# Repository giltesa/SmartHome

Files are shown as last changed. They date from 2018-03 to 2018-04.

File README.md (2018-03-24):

# SmartHome

**SmartHome** es la segunda versión de mi proyecto de **hardware** para la automatización del hogar, esta vez por comunicación inalámbrica y compatible con [**MySensors**](https://github.com/mysensors/MySensors/tree/master).

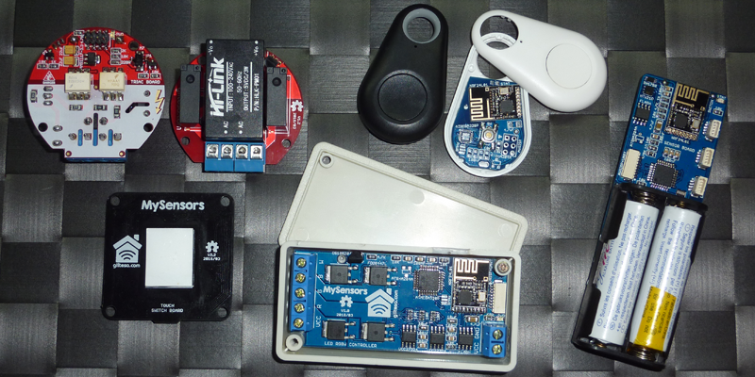
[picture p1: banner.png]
Banner SmartHome


## Introducción

En este repositorio encontraras la documentación para construir los diferentes nodos disponibles, eso incluye los esquemáticos, los circuitos, los gerbers, piezas en 3D, código fuente, etc.

La funcionalidad de los nodos varia dependiendo de la tarea para la que hayan sido construidos. Por ejemplo encontraras un nodo de interruptor táctil para sustituir los interruptores de la pared y que permite encender, apagar y *regular el brillo (en desarrollo)* de las lamparas del techo de las habitaciones. También encontraras un nodo para tomar mediciones de temperatura, humedad y luz así como capaz de detectar eventos como la apertura y cierre de puertas y ventanas. Un poco mas abajo hay disponible una lista de todos los nodos diseñados.

### Requisitos previos

Los nodos funcionan por comunicación inalámbrica RF a 2.4Ghz distinta del WiFi por lo que hace falta un Gateway capaz de convertir esa comunicación inalámbrica a cableada y viceversa, esto tiene como inconveniente que hace falta un aparato mas pero tiene como ventaja que no sobrecargaremos el router WiFi con una treintena de nodos conectados al mismo tiempo.

Además del Gateway también es necesario un software de gestión que controle todos los nodos, este software puede ser cualquiera que soporte nodos programados con la librería MySensors, en el apartado [controlador](https://www.mysensors.org/controller) hay documentada una tabla de softwares de gestión compatibles.

## Lista de nodos

Esta es la lista de todos los nodos con un estado de desarrollo avanzado pero no finalizado. Para consultar su estado actual o próximos nodos que desarrollare visitar este panel de trabajo: [Trello SmartHome](https://trello.com/b/6nWJ42Qx/smarthome)

* Interruptor táctil de relés
* Interruptor táctil de relé+triac
* Sensor multiuso
* Mando a distancia
* Regulador de luz LED RGBW

## Licencia

Este proyecto está licenciado bajo la licencia **Creative Commons** de tipo: **[Reconocimiento-NoComercial-CompartirIgual 4.0 Internacional (CC BY-NC-SA 4.0)](https://creativecommons.org/licenses/by-nc-sa/3.0/deed.es_ES)**. Consulte el archivo [LICENSE.md](LICENSE.md) para obtener más información.

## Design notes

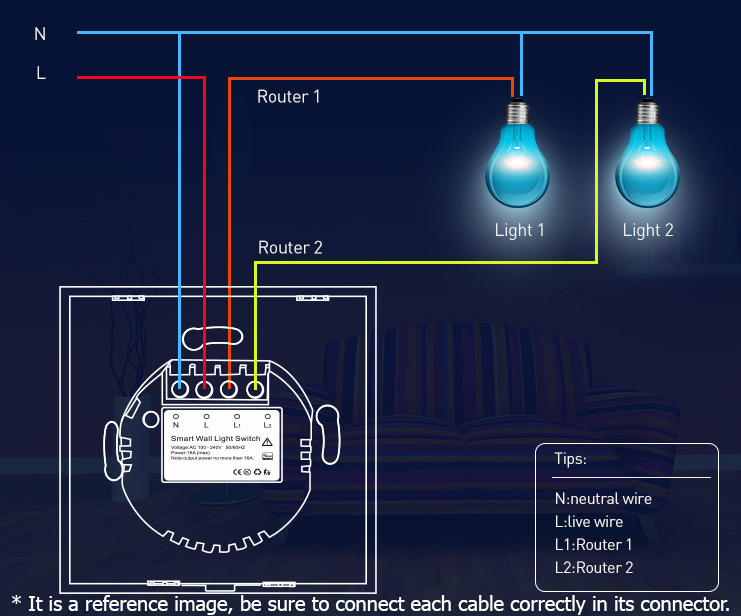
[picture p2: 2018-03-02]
2. Touch switch/4. Documentation/2. Relay Board/Pinout.png

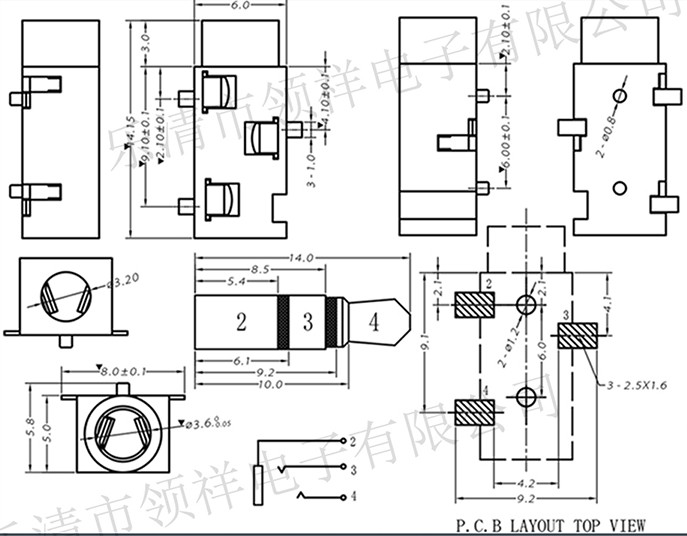
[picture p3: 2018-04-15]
7. Current sensor/4. Documentation/Pinout Jack 3.5mm.jpg

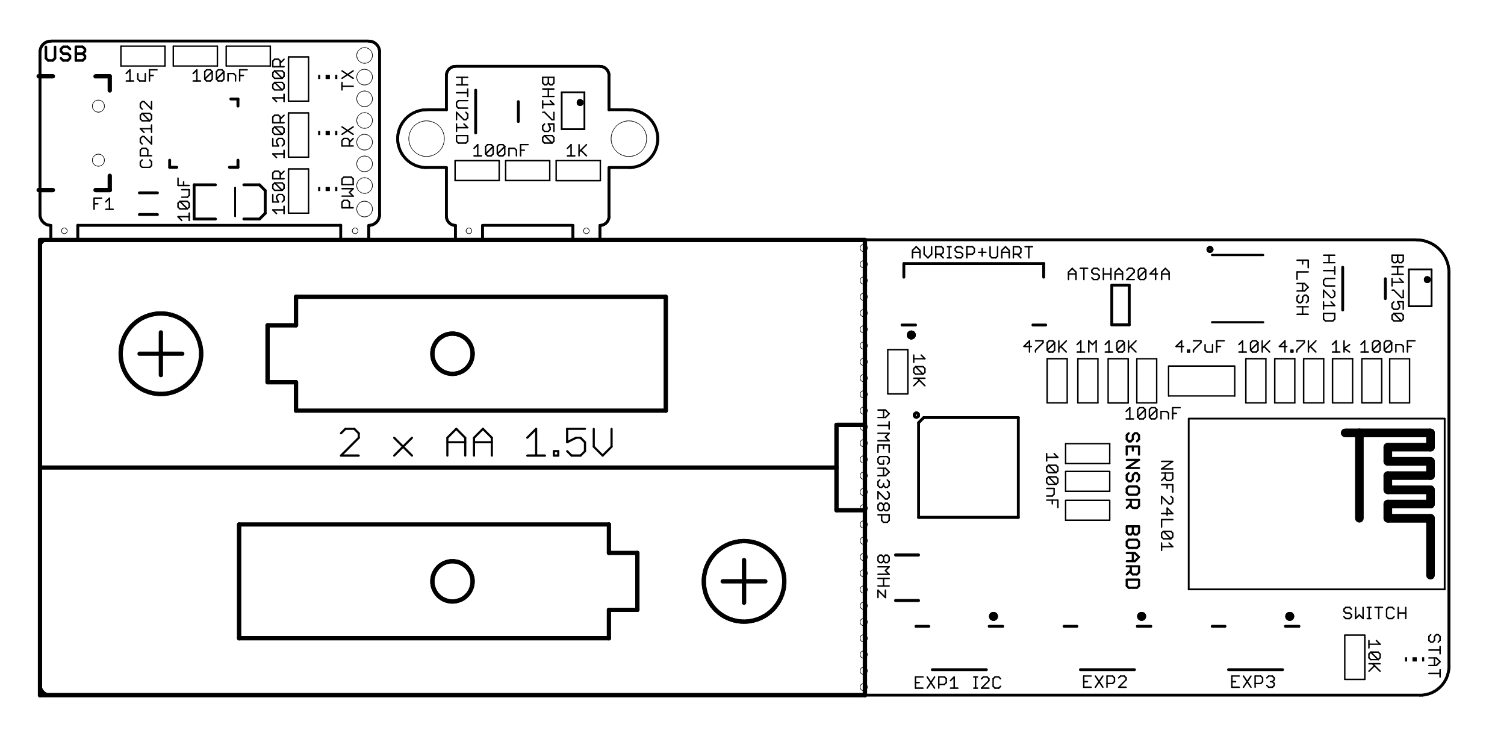
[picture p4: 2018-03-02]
3. Sensor/2. Gerbers/Images/Sensor.GTO.png

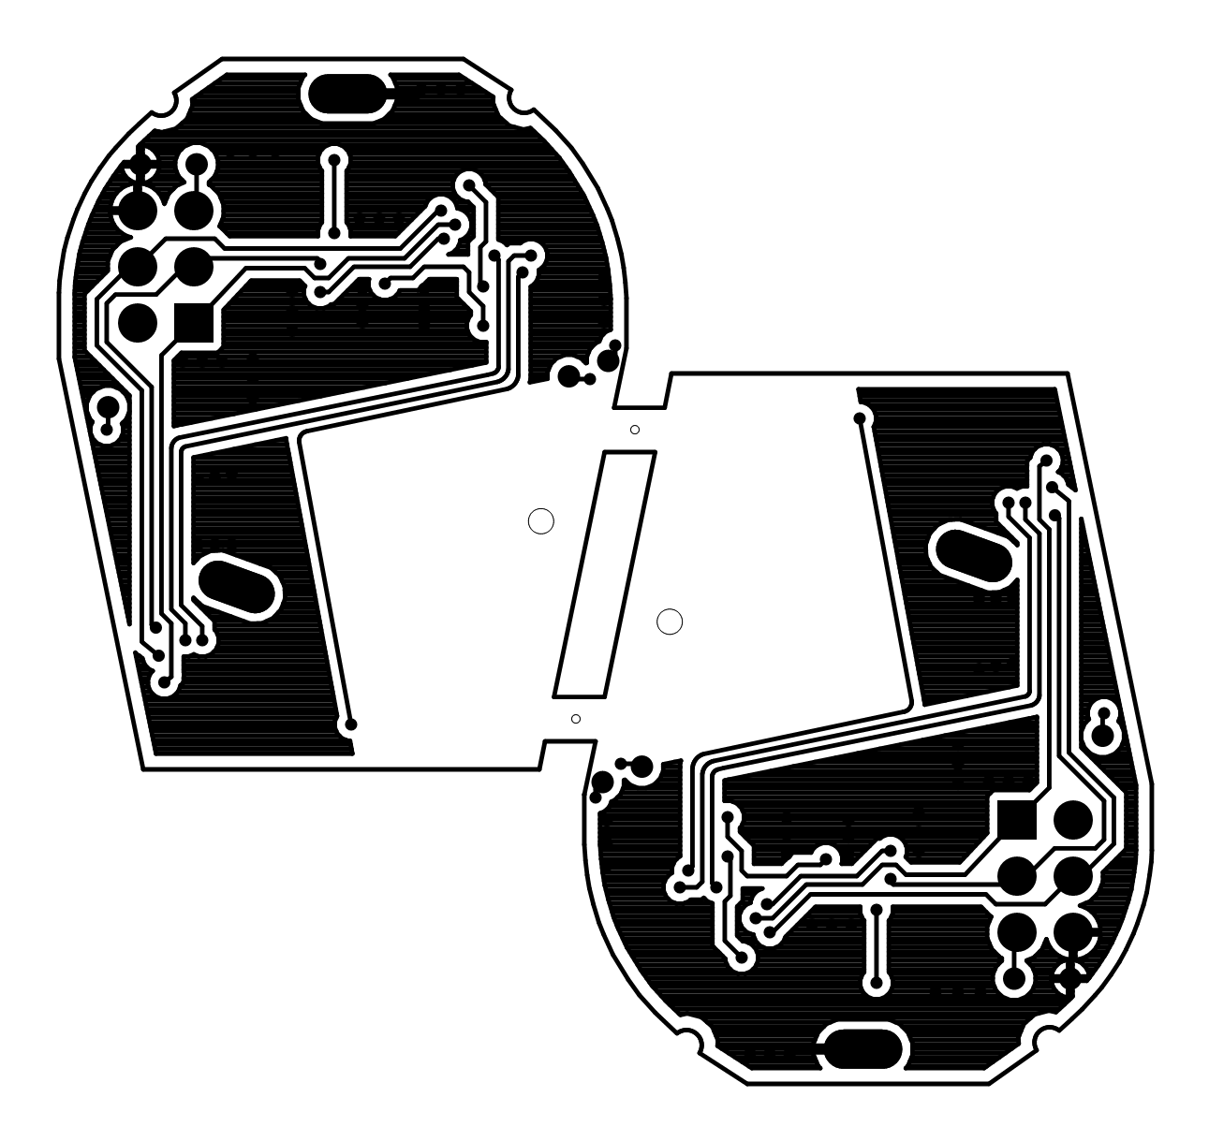
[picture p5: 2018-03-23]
4. Remote Control/2. Gerbers/Images/Remote Control - x2.GBL.png

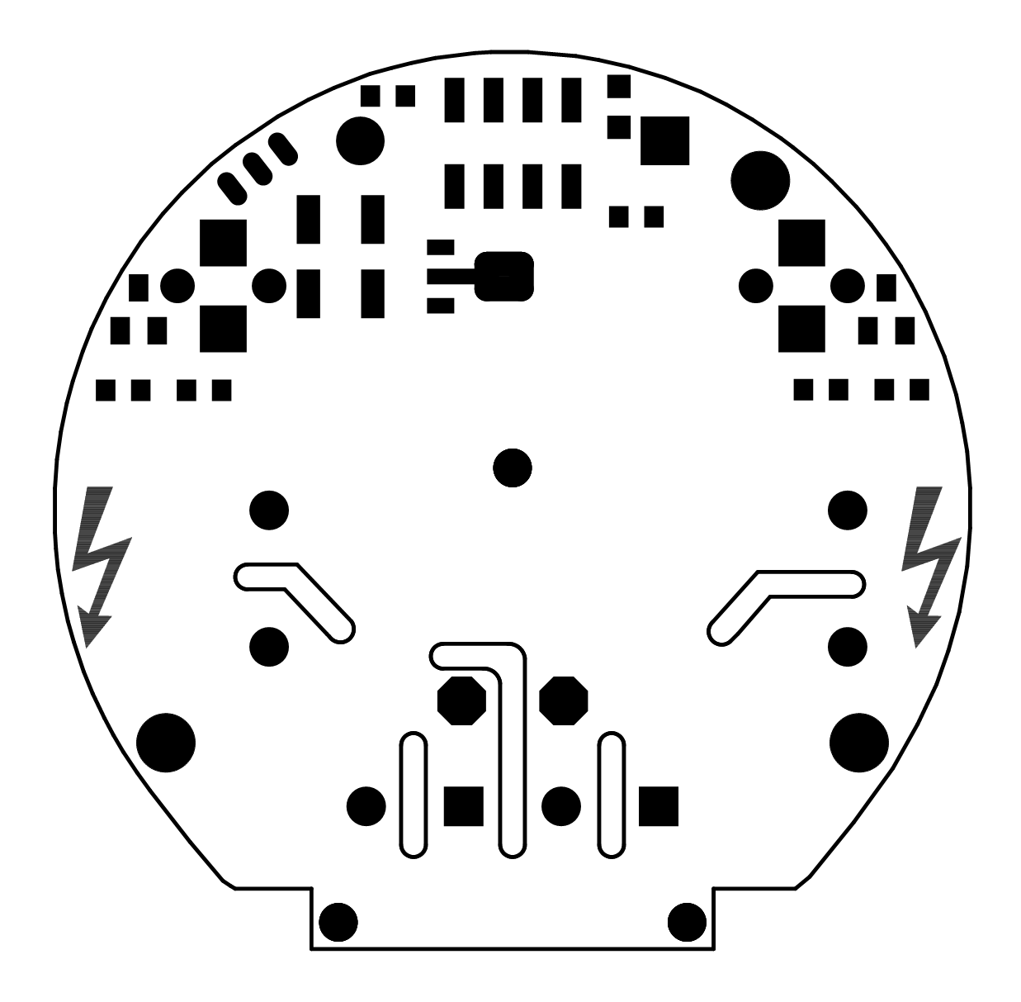
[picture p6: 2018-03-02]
2. Touch switch/2. Gerbers/2. Relay Switch/Relay Switch - 2018-03 v1.2/Images/Relay Switch.GTS.png

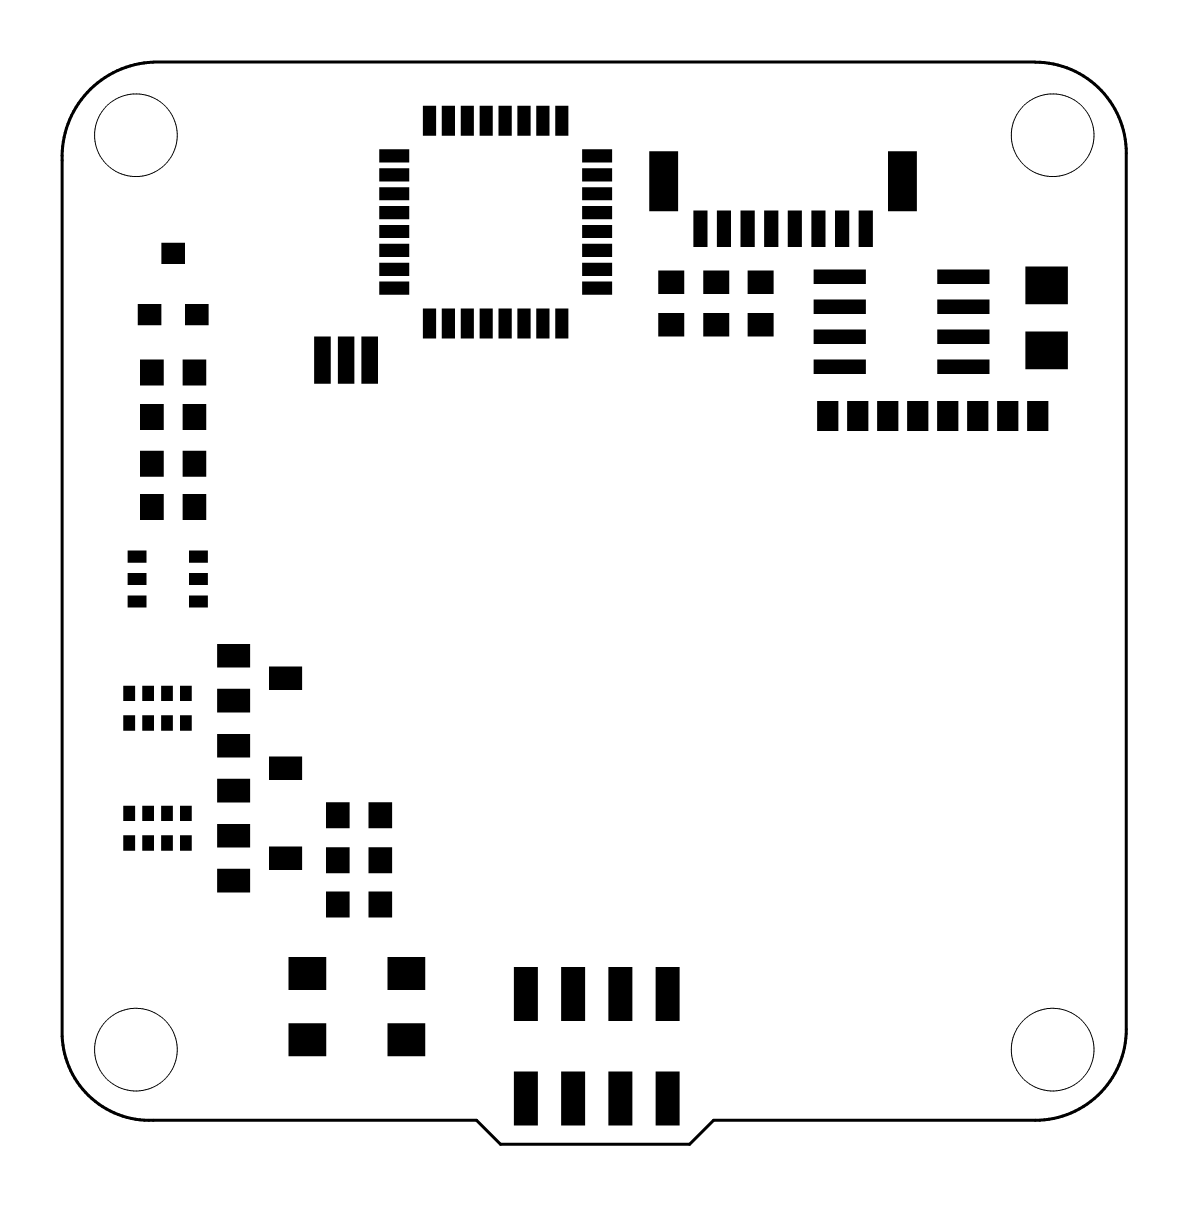
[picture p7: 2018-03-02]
2. Touch switch/2. Gerbers/1. Touch Switch/Touch Switch - 2017-12 v2.1/Images/SmartHome - Switch Touch.GTP.png

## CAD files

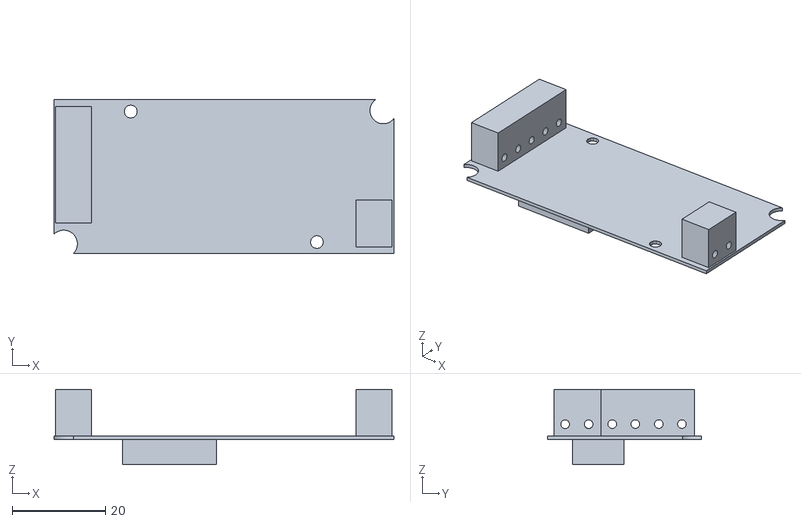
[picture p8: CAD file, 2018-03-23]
5. LED RGBW Controller/3. Renders/Sketchup/Drilling guide.stl
73.0 x 33.1 x 16.2

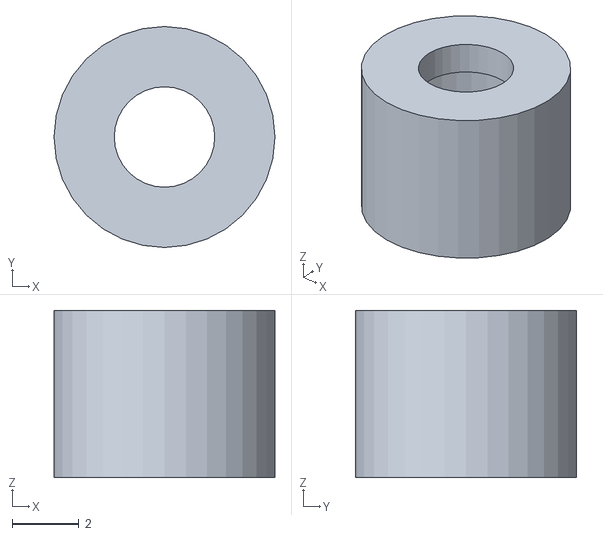
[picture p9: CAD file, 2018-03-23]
5. LED RGBW Controller/3. Renders/Sketchup/washer.stl
6.60 x 6.60 x 5.00

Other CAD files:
5. LED RGBW Controller/3. Renders/Sketchup/Drilling guide.skp
5. LED RGBW Controller/3. Renders/Sketchup/washer.skp
7. Current sensor/3. Renders/DinBox.skp

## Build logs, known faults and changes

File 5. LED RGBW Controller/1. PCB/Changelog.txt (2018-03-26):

--- YYYY/MM -------------------------------------------------------------------------------------------------

    + REMOTE CONTROL Vx.x.
        - Change the voltage regulator from 24 to 5V, if the power supply provides more than 24V will burn,
          it would be good to use one that had more margin.

--- 2018/03 INITIAL VERSION ---------------------------------------------------------------------------------

    + LED RGBW CONTROLLER V1.0.

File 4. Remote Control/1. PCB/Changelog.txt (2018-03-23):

--- 2018/04 -------------------------------------------------------------------------------------------------

    + REMOTE CONTROL V1.1.
        - Change the encapsulation of the microcontroller from QFN28 to MLF32... I got confused and it is cheaper to make the boards again than to buy the correct microcontrollers.
        - Make the PCB with 1mm thickness.
        - Change the button component from 6x6 to 5x5mm
        - Adjust the size of the PCB so that it is as close as possible to the housing.

--- 2018/03 INITIAL VERSION ---------------------------------------------------------------------------------

    + REMOTE CONTROL V1.0.

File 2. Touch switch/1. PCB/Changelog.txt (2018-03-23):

--- 2018/03 -------------------------------------------------------------------------------------------------

    + TOUCH SWITCH BOARD V2.2:
        - Change pinout.

    + RELAY SWITCH BOARD V1.2:
        - Change AC connectors by ones at an angle of 90º (and modify the plastic shell with the new design)
        - Change encapsulated for AMS1117 to SOT89 (To match the triacs PCB)

    + TRIAC SWITCH BOARD V1.0:
        - Initial version

--- 2017/12 -------------------------------------------------------------------------------------------------

    + TOUCH SWITCH BOARD V2.1:
        - Move programming connector to the inside of the board, it was colliding with the plastic housing.
        - Modify the pinout of the RGB LED, the green and blue colors of the reverse.
        - Add text that identifies the functionality of the board.

    + RELAY SWITCH BOARD V1.1:
        - Replace SSR relay with 5A mechanical relays.
        - Add text that identifies the functionality of the board.

--- 2017/10 INITIAL VERSION ---------------------------------------------------------------------------------

    + TOUCH SWITCH BOARD V2.0

    + RELAY SWITCH BOARD V1.0

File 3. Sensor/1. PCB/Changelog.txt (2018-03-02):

--- 2018/03 INITIAL VERSION ---------------------------------------------------------------------------------

    + SENSOR V1.0.

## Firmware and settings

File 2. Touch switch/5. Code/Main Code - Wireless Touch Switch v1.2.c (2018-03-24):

/**
 * Name:     Smarthome: Touch Switch Two Light
 * Autor:    Alberto Gil Tesa
 * Web:      https://giltesa.com/smarthome
 *           https://giltesa.com/?p=18460
 * License:  CC BY-NC-SA 4.0
 * Version:  1.2
 * Date:     2018/03/24
 *
 */



/**
 *  Pinout Touch Switch Board V2.2 and Relay Switch Board V1.2
 */
#define pBTN        2 //Interruption
#define pZERO       3 //Interruption (Not used)
#define pRELAY_1   A1
#define pRELAY_2   A2
#define pNRF_CE     7
#define pNRF_CS    10
#define pLED_RED    5 //PWM
#define pLED_GREEN  6 //PWM
#define pLED_BLUE   9 //PWM
#define pFLASH_CS   8
#define pDS18B20   A0
#define pATSHA204A A3



/**
 * MySensor configuration:
 */
#define MY_DEBUG                                // Enable debug prints to serial monitor
#define MY_BAUD_RATE                9600        // Serial output baud rate
#define MY_TRANSPORT_WAIT_READY_MS  1000        // Set how long to wait for transport ready in milliseconds
#define MY_RADIO_NRF24                          // Enable and select radio type attached
#define MY_RF24_CE_PIN              pNRF_CE     // Define this to change the chip enable pin from the default
#define MY_RF24_CS_PIN              pNRF_CS     // Define this to change the chip select pin from the default
//#define MY_REPEATER_FEATURE                   // Enable repeater functionality for this node
#define MY_OTA_FIRMWARE_FEATURE                 // Define this in sketch to allow safe over-the-air firmware updates
//#define MY_OTA_FLASH_SS           pFLASH_CS   // Slave select pin for external flash. (The bootloader must use the same pin)
#define MY_OTA_FLASH_JDECID         0xEF30      // https://forum.mysensors.org/topic/4267/w25x40clsnig-as-flash-for-ota

#define MS_BOARD_NAME               "Touch Switch: Two light"
#define MS_SOFTWARE_VERSION         "1.2"
#define MS_RELAY1_CHILD_ID          0
#define MS_RELAY2_CHILD_ID          1
#define MS_LEDPWM_CHILD_ID          2
#define MS_TEMP_CHILD_ID            3

#include <MySensors.h>
#include <OneWire.h>
#include <DallasTemperature.h>
#include <AsyncTaskLib.h>

MyMessage msgR1(MS_RELAY1_CHILD_ID, V_STATUS);
MyMessage msgR2(MS_RELAY2_CHILD_ID, V_STATUS);
MyMessage msgT1(MS_TEMP_CHILD_ID,   V_TEMP);

DallasTemperature ds18b20(new OneWire(pDS18B20));

AsyncTask *taskOn, *taskOff, *taskTemp;
byte brightnessLed = 255;

         const  unsigned long tDebouncePress = 50;
         const  unsigned long tWaitTwoPress  = 400;
         const  unsigned long tShortPress    = 300;
volatile static unsigned long tBtnPressed1   = 0;
volatile static unsigned long tBtn1Released1 = 0;
volatile static unsigned long tBtnPressed2   = 0;
volatile static unsigned long tBtn1Released2 = 0;
         static boolean       sBtnPressed    = false;



/**
 * For initialisations that needs to take place before MySensors transport has been setup (eg: SPI devices).
 */
void before()
{
    pinMode(pBTN,       INPUT);
    pinMode(pLED_RED,   OUTPUT);
    pinMode(pLED_GREEN, OUTPUT);
    pinMode(pLED_BLUE,  OUTPUT);
    pinMode(pRELAY_1,   OUTPUT);
    pinMode(pRELAY_2,   OUTPUT);

    attachInterrupt(digitalPinToInterrupt(pBTN), btnInterrupt,  CHANGE);

    setLedColor('0');
}



/**
 * Called once at startup, usually used to initialize sensors.
 */
void setup()
{
    ds18b20.begin();

    taskOn  = new AsyncTask(4000, [](){ setLedColor('B');   });
    taskOff = new AsyncTask(1000, [](){ refreshLedStatus(); });

    #ifdef MY_DEBUG
        taskTemp = new AsyncTask(60000, true, [](){ sendTemperature(); });
        taskTemp->Start();
    #endif

    request(MS_RELAY1_CHILD_ID, V_STATUS);
    request(MS_RELAY2_CHILD_ID, V_STATUS);
    request(MS_LEDPWM_CHILD_ID, V_DIMMER);

    //Start:
    setLedColor('R');
}



/**
 * This allows controller to re-request presentation and do re-configuring node after startup.
 */
void presentation()
{
    sendSketchInfo(MS_BOARD_NAME, MS_SOFTWARE_VERSION);

    present(MS_RELAY1_CHILD_ID, S_BINARY, "Light 1");
    present(MS_RELAY2_CHILD_ID, S_BINARY, "Light 2");
    present(MS_LEDPWM_CHILD_ID, S_DIMMER, "LED brightness");
    present(MS_TEMP_CHILD_ID,   S_TEMP,   "Internal temp");
}



/**
 * This will be called continuously after setup.
 */
void loop()
{
    #ifdef MY_DEBUG
        taskTemp->Update();
    #endif


    //In case of problems in the wireless connection, the LED flashes blue.
    if( !isTransportReady() )
    {
        if( !taskOn->IsActive() ){
            taskOn->Start();
        }
        taskOn->Update(*taskOff);
        taskOff->Update(*taskOn);
    }
    else if( taskOn->IsActive() || taskOff->IsActive() )
    {
        taskOn->Stop();
        taskOff->Stop();
        refreshLedStatus();
    }


    //Logic for the touch button.
    //Depending on the number of button presses and the duration, one or the other action is carried out:
    if( tBtn1Released1 > 0 && millis() - tBtn1Released1 > tWaitTwoPress && tBtn1Released2 == 0 ) //One pulsation
    {
        sBtnPressed = true;
        if( tBtn1Released1 - tBtnPressed1 <= tShortPress ) //Short press
        {
            digitalWrite(pRELAY_1, !digitalRead(pRELAY_1));
            send(msgR1.set(digitalRead(pRELAY_1)));
        }
        else if( tBtn1Released1 - tBtnPressed1 > tShortPress ) //Long press
        {
            boolean status = ( !digitalRead(pRELAY_1) && !digitalRead(pRELAY_2) );
            digitalWrite(pRELAY_1, status);
            digitalWrite(pRELAY_2, status);
            send(msgR1.set(status));
            send(msgR2.set(status));
        }
    }
    else if( tBtn1Released1 > 0 && tBtn1Released2 > 0 ) //Double pulsation
    {
        sBtnPressed = true;
        digitalWrite(pRELAY_2, !digitalRead(pRELAY_2));
        send(msgR2.set(digitalRead(pRELAY_2)));
    }


    if( sBtnPressed )
    {
        sBtnPressed  = false;
        tBtnPressed1 = tBtn1Released1 = tBtnPressed2 = tBtn1Released2 = 0;
        refreshLedStatus();

        #ifndef MY_DEBUG
            sendTemperature();
        #endif
    }

}



/**
 * Get the time when the button is pressed and released.
 */
void btnInterrupt()
{
    static boolean sInterrupt = false;

    noInterrupts();
    sInterrupt = !sInterrupt;

    if( sInterrupt ){
        setLedColor('0');
    }

    if( tBtn1Released1 == 0 )
    {
        if( sInterrupt ){
            tBtnPressed1 = millis();
        }else{
            tBtn1Released1 = millis();
        }
    }
    else if( tBtn1Released2 == 0 && millis() - tBtn1Released1 > tDebouncePress )
    {
        if( sInterrupt ){
            tBtnPressed2 = millis();
        }else{
            tBtn1Released2 = millis();
        }
    }

    if( !sInterrupt ){
        refreshLedStatus();
    }
    interrupts();
}



/**
 *
 */
void receive(const MyMessage &message)
{
    if( (message.sensor == MS_RELAY1_CHILD_ID || _msg.destination == 255) && message.type == V_STATUS )
    {
        digitalWrite(pRELAY_1, message.getBool());
        refreshLedStatus();
    }
    else if( message.sensor == MS_RELAY2_CHILD_ID && message.type == V_STATUS )
    {
        digitalWrite(pRELAY_2, message.getBool());
        refreshLedStatus();
    }
    else if( message.sensor == MS_LEDPWM_CHILD_ID && message.type == V_DIMMER )
    {
        brightnessLed = map(message.getInt(), 0, 100, 25, 255);
        refreshLedStatus();
    }
}



/**
 *
 */
void sendTemperature()
{
    ds18b20.requestTemperatures();
    send(msgT1.set(getControllerConfig().isMetric ? ds18b20.getTempCByIndex(0) : ds18b20.getTempFByIndex(0), 1));
}



/**
 * Sets the color of the led according to the state of the relays.
 */
void refreshLedStatus()
{
    if( digitalRead(pRELAY_1) && !digitalRead(pRELAY_2) ){
        setLedColor('G');
    }
    else if( !digitalRead(pRELAY_1) && digitalRead(pRELAY_2) ){
        setLedColor('Y');
    }
    else if( digitalRead(pRELAY_1) && digitalRead(pRELAY_2) ){
        setLedColor('W');
    }
    else if( !digitalRead(pRELAY_1) && !digitalRead(pRELAY_2) ){
        setLedColor('R');
    }
}



/**
 * Turn on the led in the indicated color.
 */
void setLedColor( char color )
{
    switch( color )
    {
        case 'R':   //RED
            analogWrite(pLED_RED,    brightnessLed);
            digitalWrite(pLED_GREEN, LOW);
            digitalWrite(pLED_BLUE,  LOW);
            break;
        case 'G':   //GREEN
            digitalWrite(pLED_RED,   LOW);
            analogWrite(pLED_GREEN,  brightnessLed);
            digitalWrite(pLED_BLUE,  LOW);
            break;
        case 'B':   //BLUE
            digitalWrite(pLED_RED,   LOW);
            digitalWrite(pLED_GREEN, LOW);
            analogWrite(pLED_BLUE,  brightnessLed);
            break;
        case 'Y':   //YELLOW
            analogWrite(pLED_RED,    brightnessLed);
            analogWrite(pLED_GREEN,  brightnessLed);
            digitalWrite(pLED_BLUE,  LOW);
            break;
        case 'W':   //WHITE
            analogWrite(pLED_RED,   brightnessLed);
            analogWrite(pLED_GREEN, brightnessLed);
            analogWrite(pLED_BLUE,  brightnessLed);
            break;
        default:    //OFF
            digitalWrite(pLED_RED,   LOW);
            digitalWrite(pLED_GREEN, LOW);
            digitalWrite(pLED_BLUE,  LOW);
            break;
    }
}

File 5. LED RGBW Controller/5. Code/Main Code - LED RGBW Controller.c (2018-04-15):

/**
 * Name:     Smarthome: LED RGBW Controller
 * Autor:    Alberto Gil Tesa
 * Web:      https://giltesa.com/smarthome
 * License:  CC BY-NC-SA 4.0
 * Version:  1.0.2
 * Date:     2018/04/05
 *
 */


/**
 *  Pinout V1.0
 */
#define pLED_RED    5 //PWM
#define pLED_GREEN  6 //PWM
#define pLED_BLUE   9 //PWM
#define pLED_WHITE  3 //PWM
#define pNRF_CE     7
#define pNRF_CS    10
#define pFLASH_CS   8
#define pDS18B20   A0
#define pATSHA204A A3



/**
 * MySensor configuration:
 */
#define MY_DEBUG                                // Enable debug prints to serial monitor
#define MY_BAUD_RATE                9600        // Serial output baud rate
#define MY_TRANSPORT_WAIT_READY_MS  1000        // Set how long to wait for transport ready in milliseconds
#define MY_RADIO_NRF24                          // Enable and select radio type attached
#define MY_RF24_CE_PIN              pNRF_CE     // Define this to change the chip enable pin from the default
#define MY_RF24_CS_PIN              pNRF_CS     // Define this to change the chip select pin from the default
//#define MY_REPEATER_FEATURE                   // Enable repeater functionality for this node
#define MY_OTA_FIRMWARE_FEATURE                 // Define this in sketch to allow safe over-the-air firmware updates
#define MY_OTA_FLASH_SS             pFLASH_CS   // Slave select pin for external flash. (The bootloader must use the same pin)
#define MY_OTA_FLASH_JDECID         0xEF30      // https://forum.mysensors.org/topic/4267/w25x40clsnig-as-flash-for-ota

#define MS_BOARD_NAME               "LED RGBW Controller"
#define MS_SOFTWARE_VERSION         "1.0.2"
#define MS_STATUS_CHILD_ID          0
#define MS_RGB_CHILD_ID             1
#define MS_RGBW_CHILD_ID            2
#define MS_WHITE_CHILD_ID           3
#define MS_TEMP_CHILD_ID            4

#include <MySensors.h>
#include <DallasTemperature.h>
#include <AsyncTaskLib.h>

MyMessage msgSTAT(MS_STATUS_CHILD_ID, V_STATUS);
MyMessage msgTEMP(MS_TEMP_CHILD_ID,   V_TEMP);

DallasTemperature ds18b20(new OneWire(pDS18B20));
AsyncTask *taskOn, *taskOff, *taskTemp;

struct RGBW{byte r, g, b, w;} led;



/**
 * For initialisations that needs to take place before MySensors transport has been setup (eg: SPI devices).
 */
void before()
{
    pinMode(pLED_RED,   OUTPUT);
    pinMode(pLED_GREEN, OUTPUT);
    pinMode(pLED_BLUE,  OUTPUT);
    pinMode(pLED_WHITE, OUTPUT);

    setLedColor('0');
}



/**
 * Called once at startup, usually used to initialize sensors.
 */
void setup()
{
    ds18b20.begin();

    taskOn  = new AsyncTask(4000, [](){ setLedColor('B'); });
    taskOff = new AsyncTask(1000, [](){ setLedColor('0'); });

    #ifdef MY_DEBUG
        taskTemp = new AsyncTask(60000, true, [](){ sendTemperature(); });
        taskTemp->Start();
    #endif

  //request(MS_STATUS_CHILD_ID, V_STATUS);
  //request(MS_RGB_CHILD_ID,    V_RGB);
  //request(MS_RGBW_CHILD_ID,   V_RGBW);
  //request(MS_WHITE_CHILD_ID,  V_DIMMER);
}



/**
 * This allows controller to re-request presentation and do re-configuring node after startup.
 */
void presentation()
{
    sendSketchInfo(MS_BOARD_NAME, MS_SOFTWARE_VERSION);

    present(MS_STATUS_CHILD_ID, S_BINARY,     "LED On/Off");
    present(MS_RGB_CHILD_ID,    S_RGB_LIGHT,  "LED RGB");
    present(MS_RGBW_CHILD_ID,   S_RGBW_LIGHT, "LED RGBW");
    present(MS_WHITE_CHILD_ID,  S_DIMMER,     "LED White");
    present(MS_TEMP_CHILD_ID,   S_TEMP,       "Temp. Int.");
}



/**
 * This will be called continuously after setup.
 */
void loop()
{
    #ifdef MY_DEBUG
        taskTemp->Update();
    #endif


    //In case of problems in the wireless connection, the LED flashes blue.
    if( !isTransportReady() )
    {
        if( !taskOn->IsActive() ){
            taskOn->Start();
        }
        taskOn->Update(*taskOff);
        taskOff->Update(*taskOn);
    }
    else if( taskOn->IsActive() || taskOff->IsActive() )
    {
        taskOn->Stop();
        taskOff->Stop();
        setLedColor('0');
    }
}



/**
 *
 */
void receive(const MyMessage &message)
{
    if( message.sensor == MS_STATUS_CHILD_ID || message.sensor == MS_RGB_CHILD_ID || message.sensor == MS_RGBW_CHILD_ID || message.sensor == MS_WHITE_CHILD_ID )
    {
        if( message.type == V_STATUS )
        {
            bool status = message.getBool();

            if( status && led.r == 0 && led.g == 0 && led.b == 0 && led.w == 0 ){
                led.w = 128;
            }

            fadeLed(status, led);
        }
        else if( message.type == V_RGB || message.type == V_RGBW )
        {
            String hex = message.getString();

            if( hex.startsWith("#") ){
                hex = hex.substring(1, hex.length());
            }

            if( hex.length() == 6 || hex.length() == 8 )
            {
                led.r = strHexToDec(hex.substring(0, 2));
                led.g = strHexToDec(hex.substring(2, 4));
                led.b = strHexToDec(hex.substring(4, 6));
                led.w = hex.length() == 8 ? strHexToDec(hex.substring(6, 8)) : 0;

                analogWrite(pLED_RED,   led.r);
                analogWrite(pLED_GREEN, led.g);
                analogWrite(pLED_BLUE,  led.b);
                analogWrite(pLED_WHITE, led.w);

                send(msgSTAT.set(led.r > 0 || led.g > 0 || led.b > 0 || led.w > 0));
            }
        }
        else if( message.type == V_DIMMER )
        {
            led.r = led.g = led.b = 0;
            led.w = map(message.getInt(), 0, 100, 0, 255);
            analogWrite(pLED_RED,   led.r);
            analogWrite(pLED_GREEN, led.g);
            analogWrite(pLED_BLUE,  led.b);
            analogWrite(pLED_WHITE, led.w);

            send(msgSTAT.set(led.w > 0));
        }

        #ifndef MY_DEBUG
            sendTemperature();
        #endif
    }
}



/**
 *
 */
byte strHexToDec(String str)
{
    char charbuf[3];
    str.toCharArray(charbuf, 3);
    return strtol(charbuf, 0, 16);
}



/**
 *
 */
void sendTemperature()
{
    ds18b20.requestTemperatures();
    send(msgTEMP.set(getControllerConfig().isMetric ? ds18b20.getTempCByIndex(0) : ds18b20.getTempFByIndex(0), 1));
}
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

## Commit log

2018-03-23 Update project
    [Drilling guide.skp, Drilling guide.stl, washer.skp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]
2018-05-24 Nuevo nodo
    Añadido nuevo nodo de medición de consumo eléctrico para cuadros
    electricos.
    [DinBox.skp]
